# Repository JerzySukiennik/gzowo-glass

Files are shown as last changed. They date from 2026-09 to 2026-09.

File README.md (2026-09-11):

# Gzowo Glass — G.L.A.S.S.

Home-built smart glasses: a see-through HUD in front of the right eye (0.96" OLED →
fold mirror → f=50 lens → 50/50 beam splitter) driven by a XIAO ESP32-S3 Sense, with a
voice assistant (Gemini Live, Polish) running on a home server.
G.L.A.S.S. = *Gzowo Like A Smart Sass*.

## Repo layout

- `cad/glass.scad` — the print-ready parametric frame (OpenSCAD 2021.01). Source of truth.
- `cad/export-all.sh` — exports every part to `cad/stl/` (build output, wiped each run).
- `cad/glass_build.py` — Blender 4.5 script: imports the STLs, adds lenses/optics/mannequin, renders stills and a turntable into `renders/`.
- `SHOPPING.md` — parts list with prices.
- `RESEARCH.md` — what other DIY smart-glasses builds got right and wrong.

## Regenerate

```bash
cad/export-all.sh
/Applications/Blender.app/Contents/MacOS/Blender -b -P cad/glass_build.py -- stills
/Applications/Blender.app/Contents/MacOS/Blender -b -P cad/glass_build.py -- turntable
```

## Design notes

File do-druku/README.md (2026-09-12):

# do-druku — v0.6 (po przeglądzie gauntlet, przed drukiem)

Sześć części + 14 × M2,5×12 (2 zawiasy + 4 pokrywka daszka + 4 + 4 pokrywki podów).
Folder jest kopią `cad/stl/`, źródłem jest `cad/glass.scad`. Co się zmieniło i dlaczego: `GAUNTLET-REPORT.md`.

| Plik | Szt. | Orientacja na stole | Podpory |
|---|---|---|---|
| `front.stl` | 1 | **DO GÓRY NOGAMI**: górne krawędzie daszka i podów na stole (otwarte komory w dół) | brak w komorach; tree pod noskówkami i pod belką między podami |
| `lid_hood.stl`, `lid_r.stl`, `lid_l.stl` | 1+1+1 | płasko | brak |
| `temple_r.stl`, `temple_l.stl` | 1+1 | na boku, występ głośnika do góry | brim, bez podpór |

PLA, 0,2 mm, 3 ścianki, 20 %. Skala 1:1 (PD = 62 roboczo). Front 200 × 68 × 42 mm.

## Co jest inaczej niż w v0.3/v0.4

- Daszek nad prawym okiem jest wyższy (34 mm) i **otwarty od góry**: tam siedzi OLED (na szynach, przesuwny 6 mm = ostrość), jedno lusterko 30×30 (między żebrami pod 45°) i soczewka (w kieszeni w podłodze, nad szybką). Szybka 25×25 wchodzi od dołu w skośną szczelinę w podłodze daszka.
- Pody otwarte od góry, pokrywki na 4 śrubki. Prawy: wzmacniacz na żebrach + przycisk w pokrywce. Lewy: bateria przy ściance + XIAO za przednią ścianką (okno kamery), USB-C przez pokrywkę.
- Zawias: śruba z góry, 4 mm gwintu w dolnej kostce, łeb wystaje 2,5 mm. Zauszniki rozchylone na zewnątrz.
- Tył płaski, rowek na kable 5×5 na tylnej ścianie belki.

## Przymiarka (bez elektroniki)

Drukuj front + zauszniki (pokrywki opcjonalnie). Sprawdź: mostek nie dotyka nosa (VD 21), noskówki leżą płasko na bokach nosa, zauszniki nie uciskają przed uszami, daszek nie zasłania więcej niż górny skrawek widzenia prawego oka, szczelina szybki ≥ 2 cm od rzęs. Zgłoś liczby, wszystko jest parametrem.

## Do potwierdzenia po dostawie części

- Pozycja obiektywu kamery i USB-C na realnym XIAO (okno i wycięcie w pokrywce lewego poda).
- Offset aktywnego pola OLED względem środka płytki (`OLED_OFF`).
- Grubość szybki i lusterka (szczeliny liczone na 1,1 i 1,6 mm).

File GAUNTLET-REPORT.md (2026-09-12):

# Gauntlet: przegląd Gzowo Glass v0.4 (2026-09-12)

Jedna runda, tylko raport (decyzja Jurka). Czterech recenzentów (optyka i geometria: Opus 5, koszyk i elektronika: Sonnet 5), potem świeży, niezależny Critic (Opus 5), który przeliczył 21 twierdzeń liczbowych od zera: 18 zgodnych, 2 błędne poprawki, 1 nieodtwarzalne. Surowe pliki: `work/gauntlet/findings/*.md`, `work/gauntlet/critic.md`.

**Wynik: STOPPED, LIMIT REACHED (jedna runda). Werdykt Critica: CONDITIONAL PASS, 72/100.** Treść recenzji jest w większości prawdziwa, ale brakowało jednej wspólnej listy i rozstrzygnięcia pięciu sprzeczności między plikami. Ta lista jest poniżej, sprzeczności rozstrzygnąłem jako orchestrator, a poprawki wprowadziłem od razu w `cad/glass.scad` jako v0.6.

## Najważniejsze wnioski

1. **Optyka v0.4 dawała obraz, ale okrojony do 44 % pikseli.** Kanały wycięte pod rozmiar OLED-a (22×11), a wiązka na soczewce potrzebuje 38×21 mm. Soczewka stała 91 mm od oka, na złym końcu toru. Do tego trzy odbicia = obraz lustrzany. Werdykt optyki: „ONLY IF".
2. **Nic nie trzymało soczewki, OLED-a ani pierwszego lusterka.** Ich „kieszenie" były wycięte w pustej komorze poda, czyli nie istniały.
3. **Front był trzema osobnymi bryłami**, sklejonymi tylko wspólną płaszczyzną (x = ±66). Slicer scaliłby je przypadkiem albo wcale.
4. **Zauszniki rozchylały się do środka** (znak kąta odwrócony), o 35 mm w głowę przy uszach.
5. Ścianki 0,24–0,6 mm w daszku (za szczelinami na lusterko i szybkę), zawias z 3,5 mm gwintu i śrubą za krótką o 1,5 mm, rowek na kable na 4–6 żył zamiast 9, mostek 4–5 mm w nosie, noskówki obrócone w złą stronę.
6. Koszyk: suma to 140,25 zł, nie „~137"; dodać JST (~4 zł) i termokurczkę (~5 zł); szybka 25×25 wystarczy (wiązka na szybce 16,7×10,2); lusterko „first surface" za 7 zł to realne ryzyko podwójnego odbicia, test latarką po dostawie.
7. Elektronika: jeden XIAO ESP32-S3 Sense wystarcza (I2C na D4/D5, I2S na D0–D2, przycisk na D3, kamera i mikrofon na stałych pinach; dwa porty I2S). Ryzyko: szczyt prądu WiFi + kamera + głośnik przy ~600 mA regulatora; czas pracy ~2 h na 500 mAh, ~4 h na 1000 mAh.

## Rozstrzygnięcia sprzeczności (orchestrator)

| Spór | Decyzja | Uzasadnienie |
|---|---|---|
| Układ optyczny: dwa lusterka (v0.4) czy jedno (optyka §3) | **Jedno.** OLED w daszku na szynie x 60–66, lusterko 45° o oś Y, soczewka w podłodze daszka, szybka pod nią | 100 % pola, 24,7°, obraz nieodwrócony, jedno lusterko taniej. Critic wykrył kolizję soczewki Ø30 z szybką 30×30 w tym układzie; rozwiązane przez szybkę 25×25 i soczewkę na z = 13,4 (przeliczone: przerwa 0,5 mm) |
| Szybka 30×30 vs 25×25 | **25×25×1,1** | Wiązka na szybce 16,7×10,2; 30 mm koliduje z soczewką |
| Liczba lusterek w koszyku | **1 × 30×30** | Wynika z układu |
| Gdzie MAX98357 | **Prawy pod, przy zewnętrznej ściance, na żebrach** | OLED nie jest już w podzie, więc spór o tor ostrości znika |
| `OLED_OFF` 4 vs ≤ 0 | **0 do czasu pomiaru suwmiarką** | Board stoi teraz w daszku między żebrami, nie w podzie; offset ustawiany po dostawie |
| Rowek na 9 żył | **Rowek 5×5 na belce 8 mm** (zamiast 6 mm) | Geometria ma rację, 3,2×3,7 mieści 4–6 żył |
| Zawias (poprawka geometrii #10 dawała 2,3 mm gwintu) | **Kostki 8 / 5 / 2, luzy 0,5, łeb wystaje** | Policzone od nowa: koniec śruby 4 mm w gwintowanej dolnej kostce, 12 mm trzonu wystarcza |
| VD 18 vs skan | **VD 21** | Mostek siedział 4–5 mm w nosie przy z = −12…−15 |
| Kolor OLED | **Biały** | Jurek, 2026-09-12 |

## Lista poprawek (wszystkie wprowadzone w v0.6, chyba że zaznaczono)

| # | Ważność | Co | Stała / moduł w SCAD | Test |
|---|---|---|---|---|
| 1 | S1 | Jeden układ optyczny z jednym lusterkiem, OLED w daszku | `MIR_C`, `LENS_Z`, `OLED_X0/X1`, `COMB`, `BS` | `part="fit"`: duchy OLED, lusterka, soczewki i szybki bez przecięć; po dostawie: pełna ramka 1 px widoczna z 4 stron |
| 2 | S1 | Pozytywne mocowania: szyny OLED, żebra lusterka, kołnierz soczewki w podłodze | `hood_holders()` | Wydruk odwrócony: soczewka trzyma się bez kleju |
| 3 | S1 | Front jako jedna bryła (daszek wchodzi 2 mm w pod, belka 8 mm) | `HOOD_X1 = 68`, `front_solid()` | Eksport STL: jedna powłoka |
| 4 | S1 | Rozchył zauszników na zewnątrz | `rotate([0,0,+s*TEMPLE_SPLAY])`, 15° | Widok z góry ze skanem: zausznik na zewnątrz głowy |
| 5 | S2 | Daszek i pody otwarte od góry, pokrywki na M2,5×12, bez cienkich ścianek za szczelinami | `hood_cavity()`, `lid_hood()`, `lid_pod()` | Ray-cast na STL: każda ścianka ≥ 1,2 mm |
| 6 | S2 | Zawias 8/5/2, luz 0,5, tylna ścianka poda 3 mm, blok kostek 6 mm w pod | `HK_*`, `BACK_W` | Sekcja z = 14: ciągły materiał od kostki do ścianek |
| 7 | S2 | Rowek 5×5 na tylnej ścianie belki 8 mm, koniec przy daszku, przelot do daszka i do prawego poda | `GROOVE`, `BAR_T` | 8 żył 1,5 mm mieści się (3×3 siatka) |
| 8 | S2 | Szybka 25×25, szczelina przez podłogę daszka z fazką (bez ostrza) | `hood_cuts()` | Ray-cast na podłodze przy szczelinie ≥ 1,2 mm |
| 9 | S2 | VD 21, noskówki obrócone w stronę policzka i pochylone | `VD`, `PAD_ANG = +40`, `PAD_TILT = 22` | Przymiarka wydruku: mostek nie dotyka nosa, noskówki płasko |
| 10 | S3 | Przycisk w pokrywce prawego poda (klatka 6,4 mm + otwór Ø4,2) | `lid_pod(1)` | Przełącznik nie wypada, klik wyczuwalny |
| 11 | S3 | Kamera: okno Ø7 + odciążenie Ø10 na wysokości płytki, USB-C w pokrywce lewego poda | `pod_cuts(-1)`, `lid_pod(-1)` | **Do potwierdzenia na realnej płytce** (pozycja złącza i obiektywu) |
| 12 | S3 | Głośnik: kieszeń z kratką 0,8 mm od strony głowy, kanał na kable wychodzi na czole zausznika | `temple_body()` | Przewody przechodzą z poda do kieszeni bez wiercenia |
| 13 | S3 | Kanał wiązki w daszku 22×14 (okno w podłodze), oś na z = 22 | `BEAM_Z`, `hood_cuts()` | Ray-trace z `optics.md` z nowymi aperturami: ≥ 95 % pikseli |
| 14 | v0.7 | Przyciemnienie **przed** szybką (płytka przed daszkiem) zamiast w obręczy | brak | Kontrast HUD:świat rośnie 0,93 → 4,7 |
| 15 | v0.7 | Szybka 70R/30T zamiast 50/50 | koszyk | Kontrast ×2,3 |
| 16 | koszyk | Dopisać JST-PH, termokurczkę; jedno lusterko; szybka 25×25 | `SHOPPING.md` | Suma po zmianie |
| 17 | firmware | Rejestr SSD1306: przy dwóch odbiciach obraz prosty, bez remapu; sprawdzić literą „R" | firmware | „R" czytelne przez szybkę |

## Czego raport nie rozstrzyga (uczciwie)

- Geometria v0.6 (nowy daszek 34 mm wysoki, otwarte komory, pokrywki) **nie była audytowana** przez recenzenta geometrii; to nowa część. Pierwszy test to eksport STL i tabela grubości ścianek, drugi to wydruk samego frontu.
- Wymiary XIAO Sense (wysokość obiektywu, pozycja USB-C) i offset aktywnego pola OLED są z datasheetów i domysłów, nie z pomiaru. Okna w lewym podzie i pokrywce poprawić po dostawie.
- Skan głowy jest w skali roboczej (PD 62). Każdy milimetr błędu PD to ±3 % wszystkich odległości.
- Jasność: HUD czytelny w pomieszczeniu i w cieniu, nie w pełnym słońcu (potrzebny byłby filtr T ≤ 0,005). To ograniczenie SSD1306, nie geometrii.

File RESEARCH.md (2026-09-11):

# Gzowo Glass — jak inni zbudowali DIY smart glasses (research 2026-09-11)

Siedem projektów, które robiły to samo co my. Co zrobili, co im nie wyszło i co z tego bierzemy.

## 1. E.D.I.T.H — AbrarFairuj, Instructables 2022 (ten od Jurka)
https://www.instructables.com/EDITH-How-Did-I-Build-a-Powerful-Smart-Glass-Under/

- **Sprzęt:** Raspberry Pi Zero (bez W!) + hub USB + dongle WiFi + dongle BT + mikrofon USB, OLED 0,96" I2C, głośnik z pinów PWM przez filtr RC + tranzystor, bateria 4000 mAh z modułem powerbanka. ~35 $.
- **Optyka:** OLED pod 22,5°, „szkło" (płaska szybka) pod 45°. **Bez soczewki.** Autor sam pisze, że użył płaskiego szkła, „żeby nie zmieniać rozmiaru obrazu" — efekt: oko musi ostrzyć na ekran z 3–5 cm, czego nie potrafi, więc obraz jest rozmyty. Dokładnie ten błąd omijamy soczewką.
- **Software:** Node na Pi, Dialogflow jako „AI", apka React Native na telefonie przesyła po Bluetooth pogodę/SMS/powiadomienia.
- **Sam przyznaje:** „bardzo duże, ciężkie, nie do noszenia", tydzień na samo postawienie OS-u, Pi Zero żre prąd (2000 mAh na chwilę). V2 „na własnej płytce z 8 rdzeniami" nigdy nie powstała.
- **Wniosek:** nasza decyzja XIAO zamiast Pi Zero i soczewka w torze to dokładnie naprawa jego dwóch największych problemów.

## 2. Arduino Glasses — Alain Mauer, hackaday.io (HMD do multimetru)
https://hackaday.io/project/12211-arduino-glasses-a-hmd-for-multimeter

- **Najlepiej policzona optyka z całej listy.** Soczewka plano-convex Ø30 mm, **f = 100 mm**, OLED **73 mm** od soczewki → obraz pozorny w odległości 27–30 cm, powiększenie 3×. Celowo 27–30 cm, bo to minimalna odległość, na którą oko ostrzy wygodnie.
- Lusterko pod 45°, uchwyt drukowany 3D. 0,96" OLED uznał za za duży, przeszedł na 0,49"/0,66" (chciał małe, my nie musimy).
- Arduino Pro Micro + HM-11 BLE, LiPo 280 mAh.
- **Problemy:** trudno kupić soczewkę (rozważał Fresnela), ekran odbijający wygiął się od ciepła, bez drukowanego uchwytu nie dało się utrzymać wyrównania.
- **Wniosek dla nas (liczby dla f = 50 mm):** OLED **bliżej niż ogniskowa** daje obraz pozorny w skończonej odległości:
  - 42 mm → obraz ~26 cm, powiększenie ~6× (OLED 22 mm szeroki wygląda jak ~14 cm na 26 cm, ~30° pola widzenia)
  - 45 mm → obraz ~45 cm, ~10×
  - 48 mm → obraz ~1,2 m
  - 50 mm → nieskończoność
  Uchwyt musi mieć **regulację 38–50 mm**, nie stałą pozycję. To potwierdza ryzyko z notatki projektu.

## 3. uGlass — moduł AR na okulary, hackaday.io
https://hackaday.io/project/167854-uglass-an-ar-module-on-your-glasses

- SSD1306 OLED + soczewka z Google Cardboard + **szkiełko mikroskopowe jako combiner**, hot glue na zwykłe okulary. nRF52832 + IMU.
- **Co się wysypało na Maker Faire:** pole widzenia za wąskie i zależne od położenia okularów na nosie („wielu ludzi nic nie widziało"); okrągła soczewka wystawała i **dotykała oka**.
- Ich wniosek: mniejszy ekran o większej gęstości pikseli, mniejsza soczewka, krótsza ogniskowa.
- **Wniosek dla nas:** soczewka jest nad okiem, nie przed nim — u nas nie dotknie oka. Combiner 30×30 mm zamiast szkiełka daje większe „okno". Oprawka drukowana na twarz Jurka zamiast klipsa = powtarzalne położenie.

## 4. Ochi — Harris Shallcross, Hackaday 2016 „why smart glasses are hard"
https://hackaday.com/2016/06/26/homemade-smart-glasses-shows-why-smart-glasses-are-hard/

- 0,95" 96×64 **kolorowy** OLED, soczewka z Cardboarda, **drukowany uchwyt przesuwany po drucianej szynie do regulacji ostrości**, STM32 + HM-11 BLE, Li-Ion + boost, apka Android.
- Lekcje: rozkład masy na głowie decyduje o komforcie; „wyświetlenie danych to połowa roboty, druga to CO i KIEDY pokazać".
- **Wniosek dla nas:** regulacja ostrości jako prowadnica z zaciskiem — bierzemy. Masa: bateria po tej samej stronie co elektronika obciąża jedno ucho; rozważyć baterię w lewym zauszniku jako przeciwwagę (kabel przez front).

## 5. Beady-i — XenonJohn, Instructables 2013
https://www.instructables.com/DIY-Google-Glasses-AKA-the-Beady-i/

- Nie DIY-optyka: przecięte gotowe okulary wideo Myvu Crystal + sprężysta opaska z headsetu. Inna droga niż nasza.
- Jedna przydatna uwaga: wyświetlacz da się ustawić bardzo blisko oka i nadal ostrzyć „na daleko", ale **za blisko = rzęsy uderzają w szkło przy mruganiu**. Combiner minimum ~20 mm od rogówki.

## 6. OpenGlass — BasedHardware (XIAO ESP32-S3 Sense, 20 $)
https://github.com/BasedHardware/OpenGlass · https://www.seeedstudio.com/blog/2024/05/23/openglass-turn-any-glasses-into-ai-smart-glasses-for-just-20-with-xiao-esp32s3-sense/

- **Ten sam moduł co nasz.** XIAO Sense + LiPo 250 mAh + drukowany klips na okulary. Zdjęcia i audio po **BLE do apki** (React Native/Expo), AI: Groq / OpenAI / Ollama moondream. Bez wyświetlacza.
- Repo zdeprecjonowane (projekt przeszedł w Omi), ale folder `firmware/` to gotowy szkic Arduino: kamera + mikrofon + BLE na XIAO Sense. Dobry punkt startowy do naszego firmware'u kamery.

## 7. Voice-Assistant-Camera-Wearable — xanderchinxyz
https://github.com/xanderchinxyz/Voice-Assistant-Camera-Wearable

- XIAO Sense, 220 mAh, drut dotykowy na D0 jako przycisk, BLE → Python na desktopie: VOSK (STT) → Groq (LLM+RAG) → pyttsx3 (TTS), moondream do obrazu. Bez wyświetlacza, bez głośnika w okularach.
- **Wniosek:** wszyscy na XIAO robią BLE do telefonu i mówią przez komputer. My idziemy krok dalej (WiFi + WebSocket + Gemini Live + HUD + głośnik w okularach) — nikt z tej listy tego nie połączył, ale każdy klocek osobno jest sprawdzony.

## Problemy powtarzające się w kilku projektach

- **Wypalanie OLED-a** po ~2 miesiącach codziennego statycznego UI → firmware: wygaszenie po ~10 s bezczynności, przesuwanie statycznych elementów o 1 px co kilka minut, jasność nie na maksa.
- **Wyrównanie optyki** to główna robota, nie elektronika. Każdy, kto nie miał drukowanego uchwytu, walczył z hot glue. Zasada: najpierw „klocki Lego" (OLED + soczewka + lusterko trzymane w ręku), dopiero potem CAD.
- **Pole widzenia** wąskie i wrażliwe na położenie na nosie → oprawka na miarę twarzy.
- **Waga i rozkład masy** — Pi Zero + 4000 mAh to koniec noszenia. XIAO + 500 mAh ≈ 25 g elektroniki.
- Audio przez BLE gubi pakiety przy odświeżaniu ekranu (u nas WiFi, nie dotyczy).
- Fresnel jako lekka alternatywa soczewki — jeśli szklana okaże się za ciężka/za gruba, opcja B.

## Co zmieniamy w planie po researchu

1. Uchwyt OLED z regulacją **38–50 mm** od soczewki (prowadnica + zacisk, jak Ochi), nie ±5 mm.
2. Combiner **≥ 20 mm** od oka (rzęsy), soczewka nad okiem nigdy w polu widzenia.
3. Firmware: **ochrona OLED** (wygaszanie, pixel shift, jasność ~60%).
4. Bateria rozważana w **lewym** zauszniku jako przeciwwaga.
5. Firmware kamery/mikrofonu na XIAO Sense: zacząć od szkicu z OpenGlass `firmware/`, nie od zera.

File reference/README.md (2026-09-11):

# reference/

Local-only inputs (gitignored): `head-scan.glb` (photogrammetry scan of Jurek, 2026-09-11), `head-aligned.blend`, `head-mm.blend`, `head-mm.stl` (aligned: origin between the pupils on the cornea plane, X right, Y forward, Z up, mm; scaled to PD = 62 provisionally), `landmarks-mm.json`.

Regenerate from the GLB with the scripts in the session scratchpad (scan_align.py, scan_refine.py) — to be moved into `tools/` when stable.

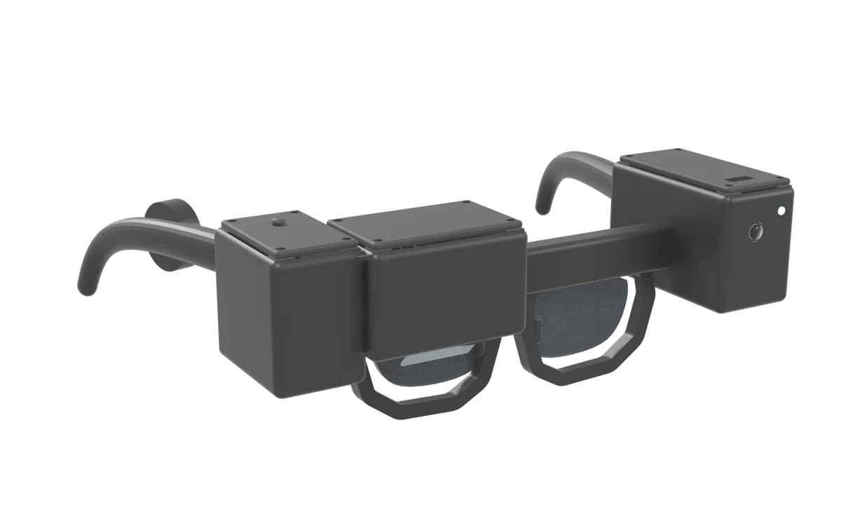
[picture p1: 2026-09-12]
docs/glass/assets/v0.6/frames/f008.webp

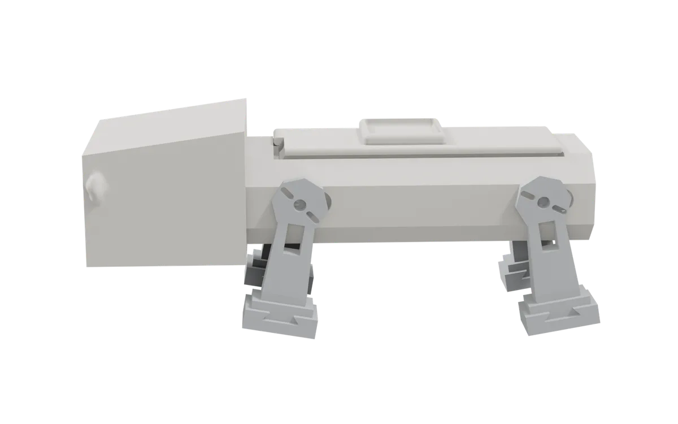
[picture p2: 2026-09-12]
docs/smendilendi/assets/v0.5/frames/f089.webp

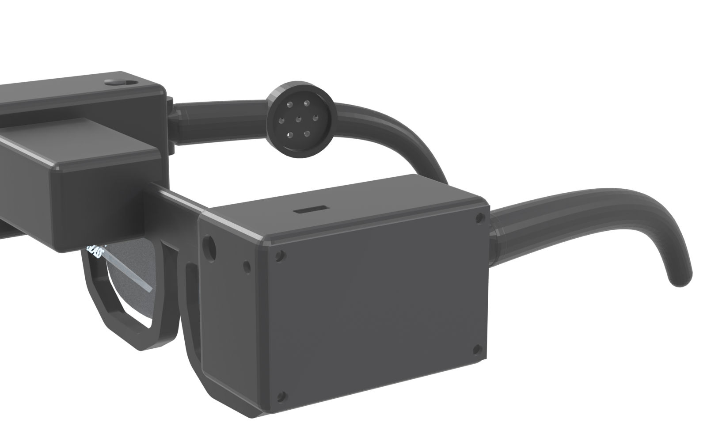
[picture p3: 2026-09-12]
renders/frames/f081.png

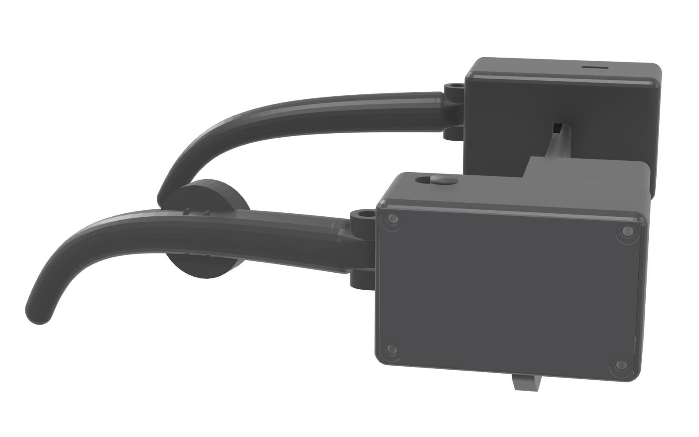
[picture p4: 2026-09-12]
renders/frames/f021.png

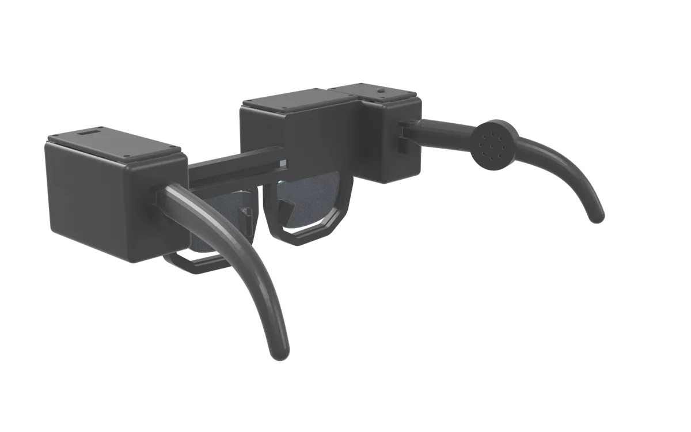
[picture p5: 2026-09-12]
docs/glass/assets/v0.6/frames/f060.webp

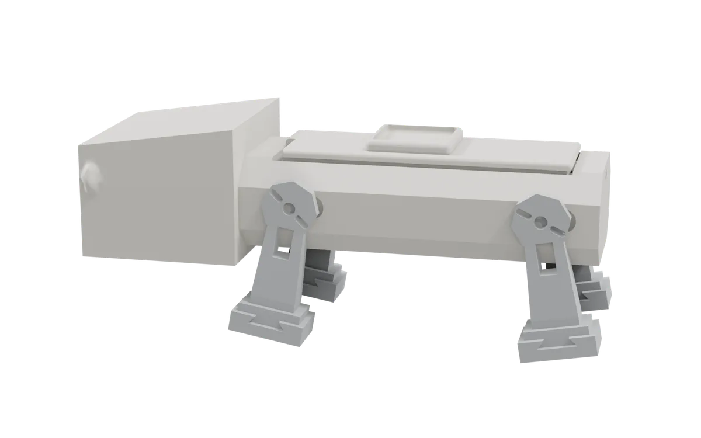
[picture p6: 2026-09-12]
docs/smendilendi/assets/v0.5/frames/f085.webp

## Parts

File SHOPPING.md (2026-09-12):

# Gzowo Glass — koszyk v1 (AliExpress, jedno zamówienie)

Ceny sprawdzone 2026-09-10 na pl.aliexpress.com (mogą się ruszać o kilka zł).
Ali ~120 zł, bateria z domu. Budżet 250 zł z dużym zapasem. Zamawia Jurek.

| # | Część | Link | Cena | Wariant do wybrania |
|---|---|---|---|---|
| 1 | **Seeed XIAO ESP32-S3 Sense** (mózg: kamera OV2640, mikrofon, 8 MB PSRAM, WiFi/BLE, ładowarka LiPo) | https://pl.aliexpress.com/item/1005006988111963.html | 65,59 zł | „1pc" (jeden wariant, kamera OV3660), dostawa 17–24 wrz |
| 2 | **OLED 0,96" 128×64 I2C SSD1306** (wyświetlacz do combinera) | https://pl.aliexpress.com/item/1005009170035050.html | 8,40 zł | kolor **biały** (Jurek, 2026-09-12), 4-pin IIC, 1 szt. |
| 3 | **Beam splitter 25×25 mm** (półprzezroczyste lustro, combiner przed okiem) | https://pl.aliexpress.com/item/1005012046261289.html (wybierz wariant 25×25, jeśli jest; inaczej szukaj „beam splitter 25x25 50/50") | ~30 zł | **25×25 mm**, 50/50, grubość ≤ 1,5 mm (v0.6: 30 mm kolidowało z soczewką; wiązka na szybce ma 17×10) |
| 4 | **Soczewka Ø30 mm, f = 50 mm** (dwuwypukła, szkło) | https://pl.aliexpress.com/item/1005004213353520.html | ~3 zł | wariant **D30mm FL50mm** (25 mm nie ma w tym listingu; 30 jest OK) |
| 5 | **Wzmacniacz I2S MAX98357** (dźwięk z ESP32 do głośnika) | https://pl.aliexpress.com/item/1005009356741606.html | 5,51 zł | 1 szt. |
| 6 | **Głośnik 20 mm, 8 Ω, 1 W, ultracienki 3,6 mm** (2 szt. w paczce, zapas) | https://pl.aliexpress.com/item/1005009193787692.html | 3,84 zł | 20×3,6 mm |
| 7 | **LiPo 3,7 V, 300–1000 mAh — Z DOMU** (Ali nie wysyła ogniw do PL, Botland = płatna dostawa). Każde ogniwo 1S z drona/powerbanka/słuchawek; ważne: 1 cela 3,7 V, nie 7,4 V | — | 0 zł | jak nic nie znajdziesz: Botland Akyga 620 mAh 40×20×8 mm, 20,90 zł (AKU-15606) |
| 9 | **Mikroprzyciski 6×6 mm tact, 20 szt.** (przycisk na podzie) | https://pl.aliexpress.com/item/1005005845072975.html | 3,73 zł | 6×6×5 mm lub 6×6×7 mm |
| 10 | **Lusterko powierzchniowe (first surface mirror) 30×30 mm, 1 szt.** — w daszku, zawraca wiązkę z OLED-a w dół na szybkę (v0.6: jedno lusterko zamiast dwóch) | szukaj na Ali: „first surface mirror 30x30" (~5–8 zł) | ~7 zł | 30×30, ≤ 2 mm, **powierzchniowe** (zwykłe lusterko daje podwójne odbicie; test po dostawie: latarka pod kątem, ma być jedno odbicie) |
| 11 | **Złączki JST-PH 2-pin** (bateria odłączalna) | Ali: „JST PH 2.0 2pin connector" | ~4 zł | 10 par |
| 12 | **Termokurczka, zestaw** (14 lutów w ciasnym podzie) | Ali: „heat shrink tube kit" | ~5 zł | 1–4 mm |
| | **Razem** | | **~137 zł** (samo Ali) | |

## Zanim klikniesz „kup"

- **Poz. 1 — zmiana 2026-09-10 wieczorem.** Pierwotny link (4000011805115, „45,49 zł") pokazywał domyślnie **samo złącze pinowe za 2,09 zł**, a dostawę 18 lis – 3 gru. Zastąpiony listingiem z jednym wariantem, 1000+ sprzedanych, dostawa w tydzień. Kamera OV3660 (2048×1536) zamiast OV2640 — dla nas tylko lepiej.
- **Sprawdzaj datę dostawy przy KAŻDEJ pozycji.** Ali sortuje po cenie z najtańszego wariantu (goldpiny, sam kabel, 1 szt. z partii), więc niska cena na liście nie znaczy niska cena tego, co chcemy. Zasada: po wybraniu wariantu cena i „Dostawa: …" mają wyglądać rozsądnie, inaczej szukaj innego sprzedawcy tego samego produktu.
- **Poz. 7, bateria — z domu.** Sprawdzone 2026-09-11: żaden LiPo z Ali nie wysyła do Polski, a Botland liczy za dostawę. Jurek szuka ogniwa w domu. Wymagania: **jedna cela Li-Po/Li-Ion 3,7 V** (na naklejce 3.7V, nie 7.4V), 300–1000 mAh, najlepiej płaski „pouch" do 9 mm grubości, z dwoma przewodami. Ogniwo 18650 też zadziała, tylko nie zmieści się w zauszniku — do testów na biurku ok.
- **Przewody:** zamiast silikonowych 28 AWG używamy starych jumperów F-F/M-M z uciętymi końcówkami (24–26 AWG, w v1 wystarczy). Pozycja usunięta z koszyka.
- **Poz. 3, beam splitter:** jeśli 36 zł boli, tańsza alternatywa to 50:50 K9 za 31,33 zł (https://pl.aliexpress.com/item/1005010313219927.html), ale sprawdź w opisie rozmiar — potrzebujemy min. 25×25 mm.
- **Głośnik:** najpierw sprawdź szufladę. Jeśli masz jakikolwiek 8 Ω, poz. 6 odpada (i tak 3,84 zł, więc zapas nie boli).

## Czego NIE zamawiamy z Ali (masz / robisz sam)

- **Ciemne „szkła" oprawki** — najtańsze okulary przeciwsłoneczne z Pepco/Action (5–10 zł) i wycinamy z nich soczewki pod wydruk. Kolor nieistotny, chodzi o kontrast HUD-u.
- **Filament** — X1C, PLA czarny albo matowy ciemnoszary.
- **Włącznik zasilania** — nie potrzebny: przytrzymanie przycisku = deep sleep. XIAO w deep sleep ciągnie tyle, że 500 mAh starcza na tygodnie czuwania.
- **Kabel USB-C** — do wgrywania firmware i ładowania, masz.

## Po dostawie — pierwszy test w 30 minut

1. XIAO + OLED (4 przewody: 3V3, GND, SDA→D4, SCL→D5) → wgrać test „Hello GLASS".
2. OLED + soczewka + beam splitter trzymane w ręku pod 45° → czy widać ostry napis „w powietrzu"? Odległość OLED↔soczewka ≈ 45–50 mm. To rozstrzyga geometrię oprawki zanim cokolwiek wydrukujemy.

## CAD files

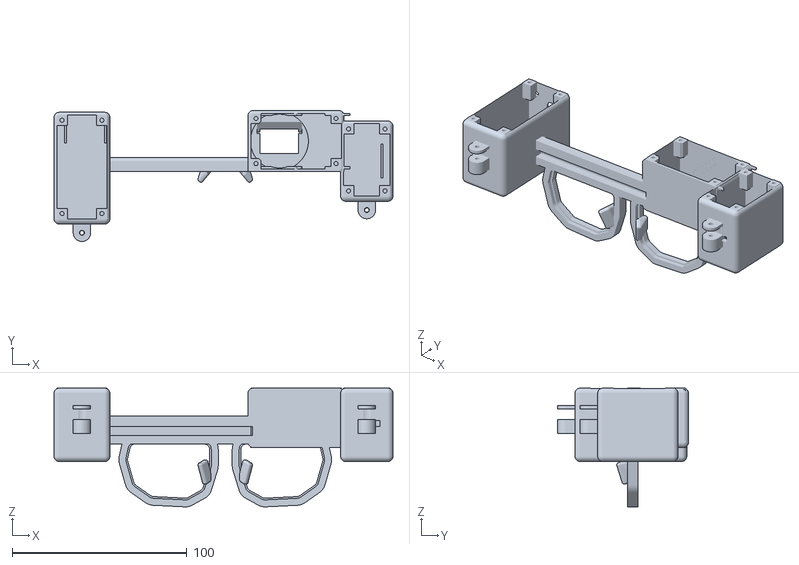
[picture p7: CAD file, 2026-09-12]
do-druku/front.stl
194.0 x 75.0 x 68.0

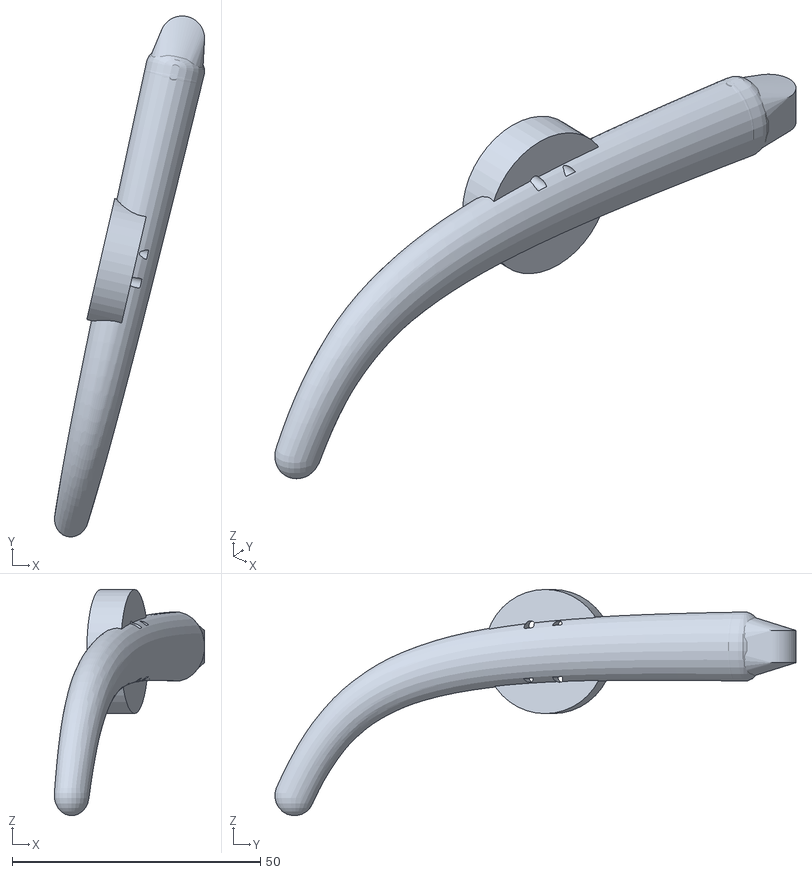
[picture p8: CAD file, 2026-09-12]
glass-fit-test-v0.4/temple_r.stl
30.2 x 104.9 x 45.5

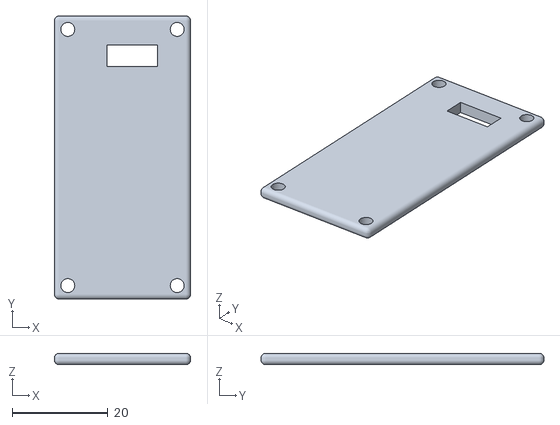
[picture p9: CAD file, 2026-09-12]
do-druku/lid_l.stl
28.4 x 59.0 x 2.40

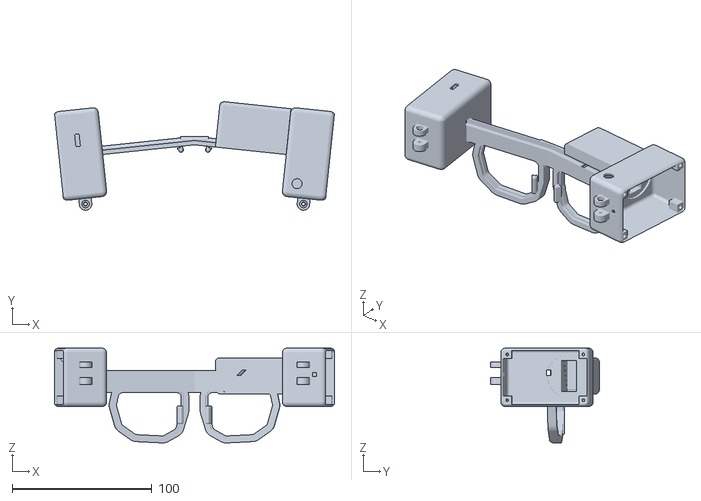
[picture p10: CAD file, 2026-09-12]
glass-fit-test-v0.4/front.stl
200.5 x 77.8 x 67.9

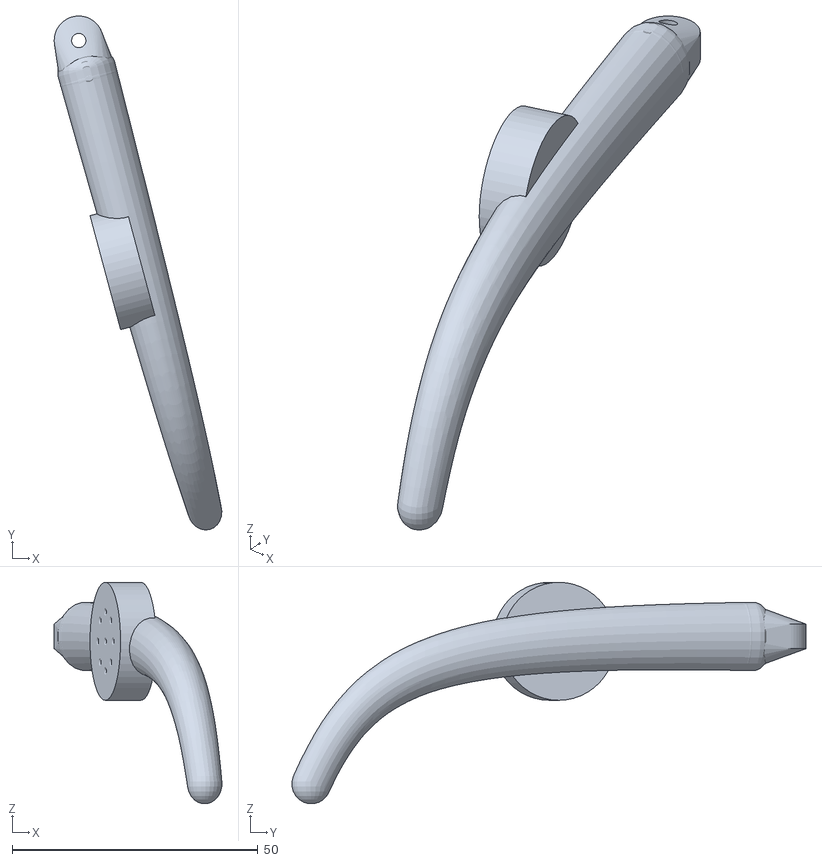
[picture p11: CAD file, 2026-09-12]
do-druku/temple_r.stl
34.1 x 104.6 x 45.0

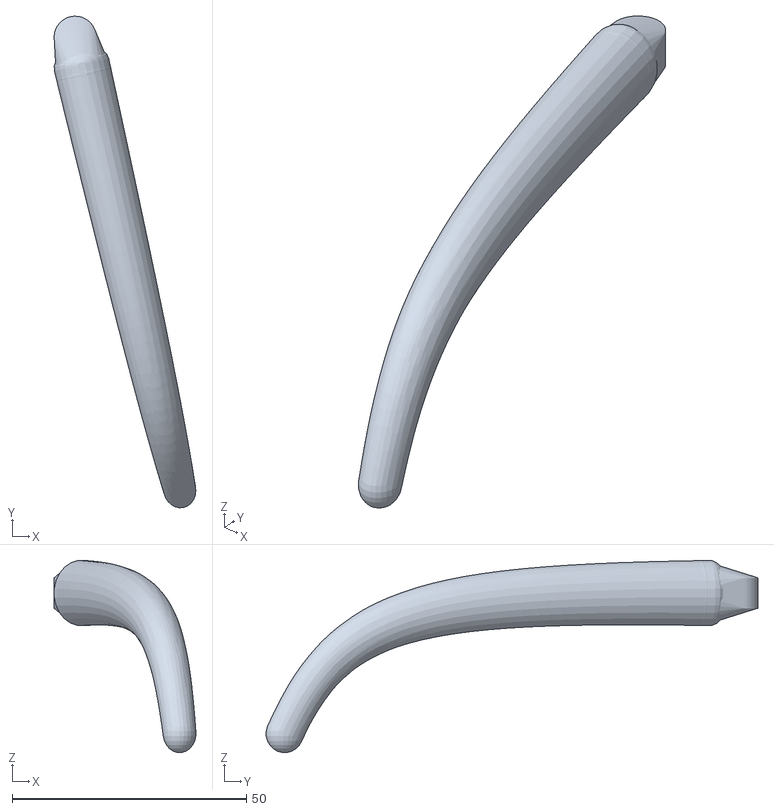
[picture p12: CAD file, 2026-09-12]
glass-fit-test-v0.4/temple_l.stl
30.2 x 104.9 x 41.0

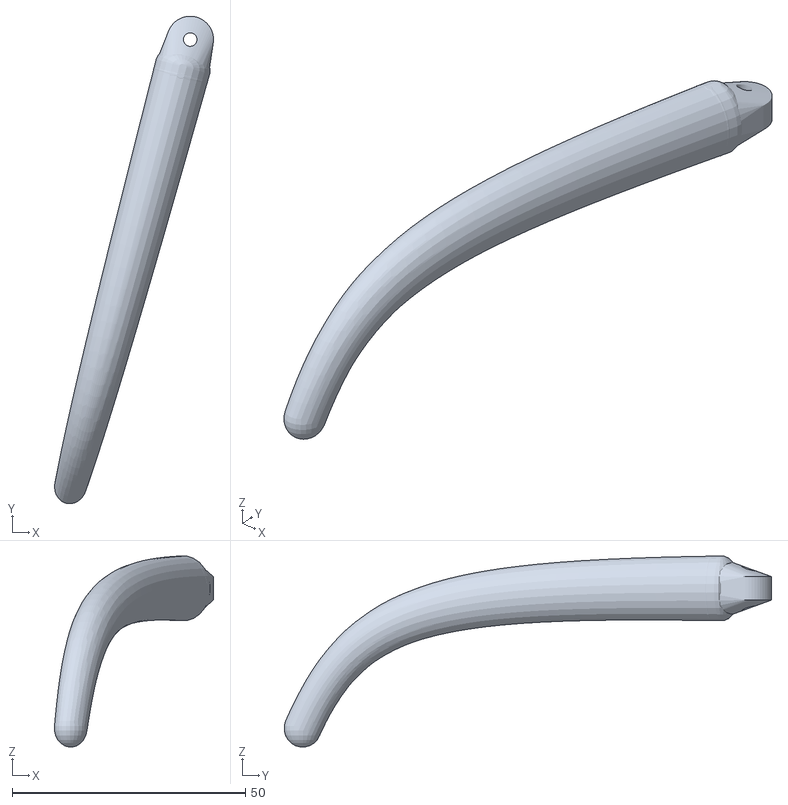
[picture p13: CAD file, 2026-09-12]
do-druku/temple_l.stl
34.1 x 104.6 x 41.0

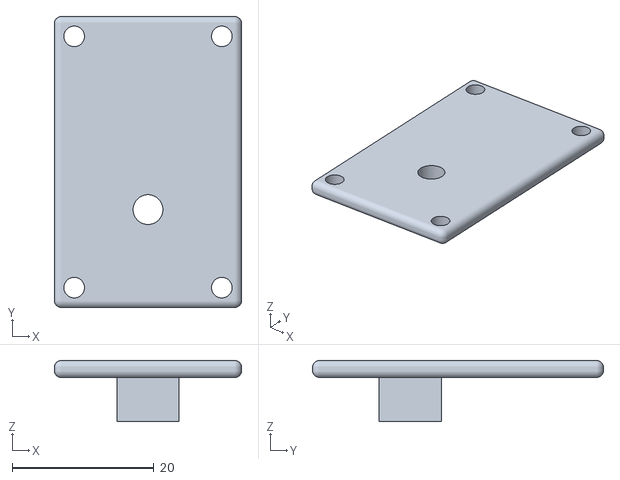
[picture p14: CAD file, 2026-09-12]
do-druku/lid_r.stl
26.4 x 41.0 x 8.60

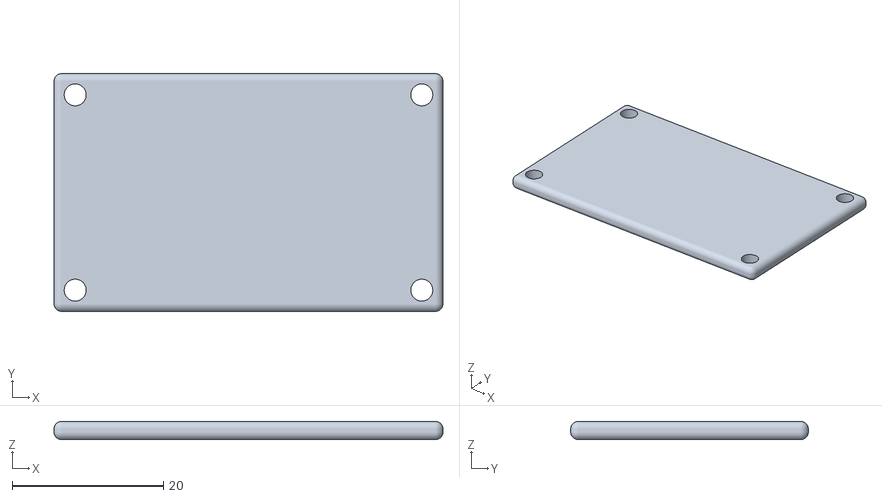
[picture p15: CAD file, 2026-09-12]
do-druku/lid_hood.stl
51.4 x 31.4 x 2.40

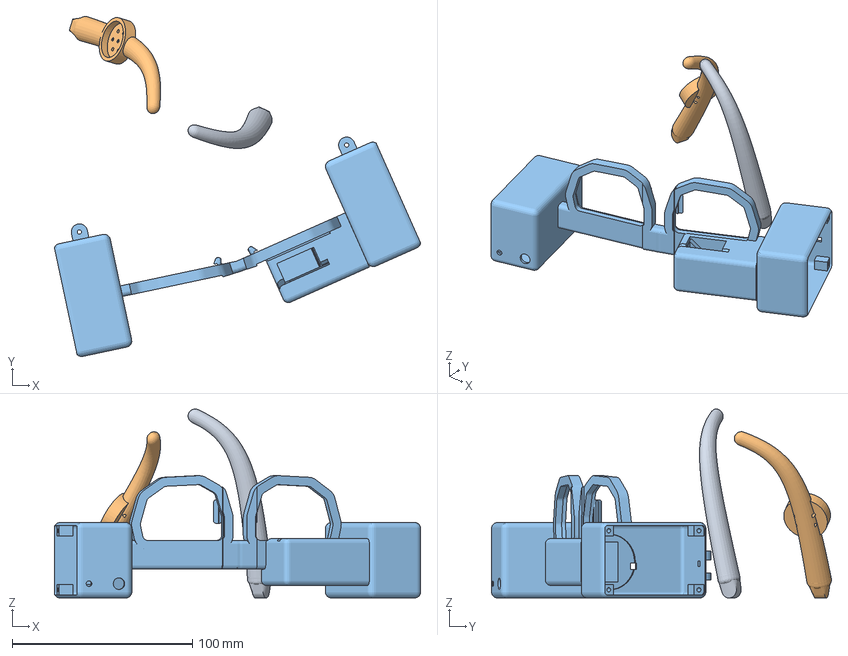
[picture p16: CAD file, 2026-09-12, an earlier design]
glass-fit-test-v0.2/front.3mf
203.3 x 188.7 x 104.9 mm
temple_l.stl
temple_r.stl
front.stl

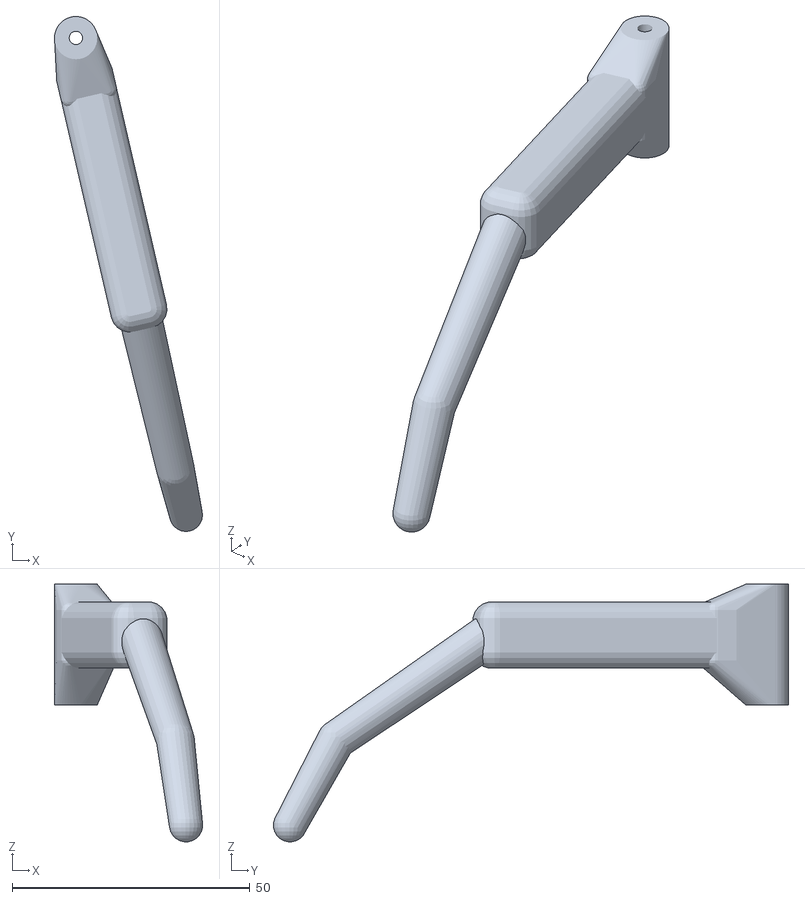
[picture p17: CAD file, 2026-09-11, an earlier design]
glass-fit-test-v0.2/temple_l.stl
31.1 x 108.3 x 54.2

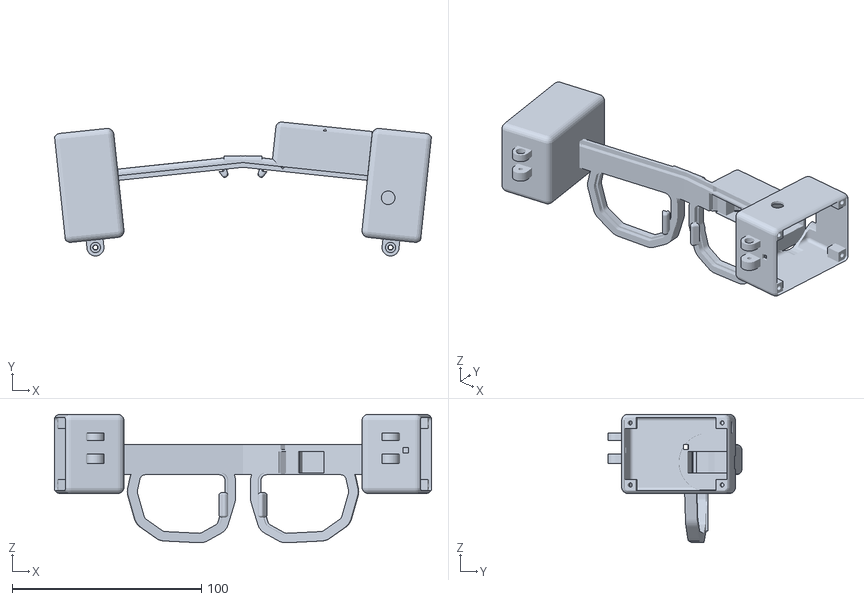
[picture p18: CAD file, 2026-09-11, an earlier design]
glass-fit-test-v0.3/front.stl
199.3 x 70.8 x 67.9

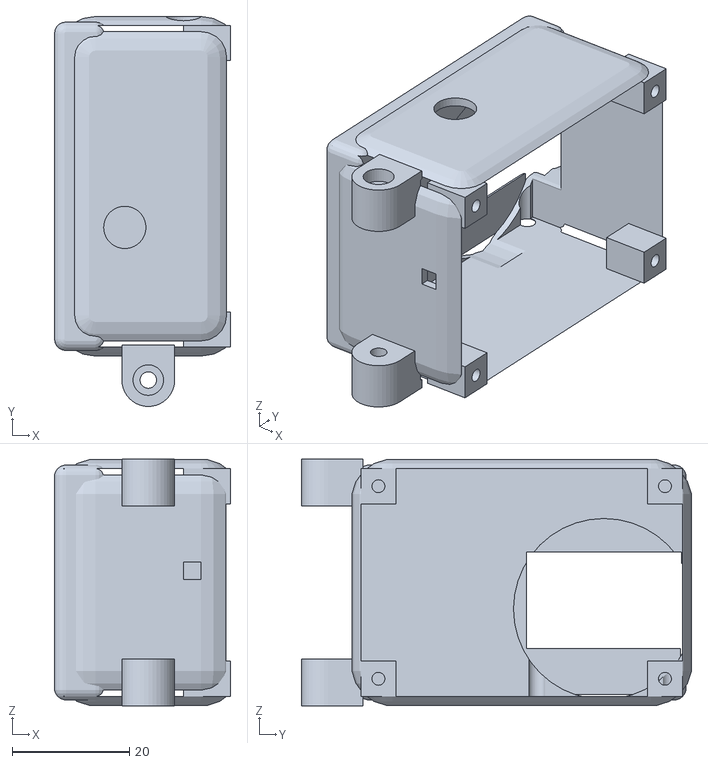
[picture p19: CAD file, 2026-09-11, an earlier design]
glass-fit-test-v0.2/pod_r.stl
30.0 x 66.4 x 42.0

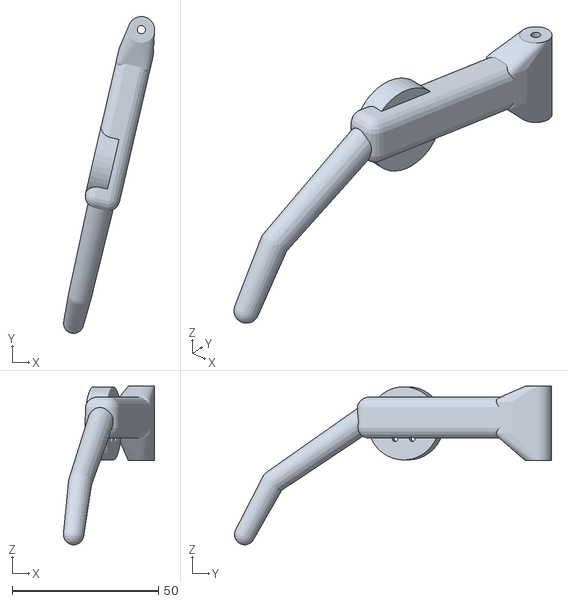
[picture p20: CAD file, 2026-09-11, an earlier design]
glass-fit-test-v0.2/temple_r.stl
31.1 x 108.3 x 54.2

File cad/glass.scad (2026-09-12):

// Gzowo Glass v0.6 — print-ready parametric frame (OpenSCAD 2021.01)
// ---------------------------------------------------------------------------
// Frame of reference (mm): X = wearer's right, Y = forward (away from the
// face), Z = up. The right pupil axis is the line (PD/2, *, 0). The back face
// of the front frame is the plane y = 0; the cornea sits at y = -VD.
//
// v0.6 rewrite after the gauntlet review (work/gauntlet/findings):
//   * SINGLE-FOLD OPTICS. The OLED stands in the hood (screen facing -X, long
//     axis along Z) on a slide rail x 60..66 (focus). One first-surface mirror
//     at 45° about Y turns the beam down; the lens f=50 sits in the hood floor
//     right above the beam splitter; the splitter (25x25) is tilted 45° about
//     X on the pupil axis. Two reflections -> upright, un-mirrored image.
//     do = 38..44 mm, lens->eye 47 mm, FOV ~24.7° x 12.5°, image 20..39 cm.
//   * Everything that holds a part is a POSITIVE feature (rails, ribs, floor
//     boss), never a slot that thins a 1.6 mm wall.
//   * The hood and both pods are open at the TOP and closed by lids (M2.5x12,
//     tapped bosses). Print the front UPSIDE DOWN (+Z on the bed): the open
//     cavities face the bed, so the front needs no internal supports.
//   * Pods are fused into the bar/hood with a 2 mm overlap (one solid).
//   * Hinge: bottom knuckle 8 (tapped), temple 5, top 2, gaps 0.5, M2.5x12
//     from the top, 4 mm of thread, head proud. Temples splay OUTWARD.
//   * Wire groove 5x5 on the back of a thicker (8 mm) bar, ends at the hood.
//   * Tinted lens in front of the combiner is a v0.7 item (contrast x5).
// Electronics: LEFT pod = XIAO ESP32-S3 Sense (camera front, USB-C up) +
//   battery. RIGHT pod = MAX98357 + button (in the lid). HOOD = OLED + mirror + lens.
// ---------------------------------------------------------------------------

part = "assembly";   // front | lid_hood | lid_r | lid_l | temple_r | temple_l | assembly | fit | layout | exploded
show_parts = true;   // ghost electronics/optics in assembly/fit
show_head = true;    // ghost of Jurek's head scan (reference/head2-mm.stl)
head_file = "../reference/head2-mm.stl";
$fn = 48;

// ------------------------------------------------------------ head / fit ---
PD       = 62;    // pupil distance (provisional; scan scaled to this)
VD       = 21;    // vertex distance: cornea -> frame back (v0.6: 18 -> 21, the bridge sat inside the nose)
DBL      = 18;    // distance between lenses
PAD_X    = 11.5;  // nose pad centre x
PAD_ANG  = 40;    // pad face angle about Z (deg): face points outward-and-forward like the nose flank
PAD_TILT = 22;    // pad face tilt about X (deg): flank leans back toward the eye
TEMPLE_L = 63;    // hinge -> start of the ear bend
EAR_DROP = 24;    // temple z -> ear top
TEMPLE_SPLAY = 15; // deg, temples open OUTWARD from the hinge (v0.4 had the sign inverted)
EX       = PD/2;

// ------------------------------------------------------- component sizes ---
XIAO     = [21, 17.8, 15];      // XIAO ESP32-S3 Sense stack incl. camera board (x, y footprint; z height of the stack)
OLED_PCB = [27.3, 27.3, 4.3];   // 0.96" I2C module board (w, h, thickness incl. pins). Active area 21.7x10.9.
AMP      = [19.4, 17.8, 3.2];   // MAX98357 breakout
SPK_D    = 20;  SPK_T = 3.6;    // speaker
BS       = [25, 25, 1.1];       // beam splitter plate (v0.6: 25x25; a 30 mm plate collided with the lens)
MIR      = [30, 30, 1.6];       // first-surface mirror, 1 pc
LENS_D   = 30;  LENS_T = 6.5;   // biconvex f=50
BTN      = [6, 6, 5];           // tact switch body
BAT      = [40, 20, 8];         // battery pocket (y, z, x): edit when the cell is known
S_TAP    = 2.4;  S_CLR = 2.9;  S_HEAD = 5.4;  // M2.5x12 in PLA
CLR      = 0.4;  WALL = 1.6;

// ---------------------------------------------------------------- layout ---
FRONT_T  = 6;                  // rim plate depth (y 0..6)
BAR_T    = 8;                  // brow bar depth (y 0..8): the 5x5 wire groove leaves a 3 mm web
BAR_Z0   = 6;   BAR_Z1 = 22;   // brow bar z-range
GROOVE   = [5, 5];             // wire groove w (z) x d (y), on the back of the bar
GROOVE_Z = 11;
// hood (right, over the eye): OLED + mirror + lens, open at the top
HOOD_X0  = 13;  HOOD_X1 = 68;  // x 13..68 (68 = 2 mm INTO the right pod -> fused); 13 so the Ø30.8 lens pocket leaves a 2 mm end wall
HOOD_Y1  = 35;                 // depth y 0..35 (lens pocket Ø30.8 around y = 17.5 leaves 2 mm walls)
HOOD_Z0  = 4;   HOOD_Z1 = 38;  // z 4..38
BEAM_Z   = 22;                 // optical axis height in the hood
AX_Y     = 17.5;               // optical axis y (mirror, lens, splitter all on y = 17.5)
MIR_C    = [EX, AX_Y, BEAM_Z]; // mirror centre; plane at 45° about Y turns the -X beam to -Z
LENS_Z   = 13.4;               // lens centre z (axis Z)
COMB     = [EX, AX_Y, 0];      // splitter centre on the pupil axis, tilted 45° about X, top toward +Y
OLED_X0  = 60;  OLED_X1 = 66;  // OLED slide range (screen face x): do = (x-EX) + (BEAM_Z-LENS_Z) = 37.1..43.1
OLED_X   = 63;                 // nominal -> do = 40.1
// pods
POD_R    = [30, 46, 42];       // right pod (amp + button + wires)
POD_L    = [32, 64, 42];       // left pod (XIAO + battery)
POD_Z0   = -4;
POD_RX   = 66 + POD_R[0]/2;    // right pod centre x (inner wall at 66)
POD_LX   = -(66 + POD_L[0]/2);
POD_RY   = 6;                  // right pod y-range -17..29
POD_LY   = 2;                  // left pod y-range -30..34
// hinge, M2.5x12 from the top: bottom knuckle 8 tapped, temple 5, top 2, gaps 0.5 -> 4 mm of thread, head proud
HK_Z0 = 12; HK_BOT = 8; HK_TEMPLE = 5; HK_TOP = 2; HK_GAP = 0.5;
HK_R  = 5;                     // knuckle radius (bore 2.9 -> 3.5 mm wall)
TEMPLE_W = 12;  TEMPLE_H = 14;
LID_T    = 2.4;
BACK_W   = WALL + 1.4;         // pod back wall 3 mm (carries the hinge)

// --------------------------------------------------------------- helpers ---
module rbox(size, r=2) { hull() for (i=[-1,1], j=[-1,1], k=[-1,1]) translate([i*(size[0]/2-r), j*(size[1]/2-r), k*(size[2]/2-r)]) sphere(r=r, $fn=48); }
module rboxc(p, size, r=2) translate(p + size/2) rbox(size, r);
module plate(d) rotate([90,0,0]) translate([0,0,-d]) linear_extrude(height=d) children(); // 2D (x,z) -> +y 0..d
module lens2d(mir=false) scale([mir ? -1 : 1, 1]) offset(r=3) offset(r=-3)
    polygon([[DBL/2,6],[54,6],[56,-3],[52,-17],[42,-24],[22,-25],[DBL/2+4,-20],[DBL/2,-7]]);
module tap(l)  cylinder(d=S_TAP, h=l);
module clr(l)  cylinder(d=S_CLR, h=l);
module head(l=3) cylinder(d=S_HEAD, h=l);
function pod_c(s)   = s>0 ? [POD_RX, POD_RY, POD_Z0+POD_R[2]/2] : [POD_LX, POD_LY, POD_Z0+POD_L[2]/2];
function pod_sz(s)  = s>0 ? POD_R : POD_L;
function hinge_x(s) = pod_c(s)[0];
function hinge_y(s) = pod_c(s)[1] - pod_sz(s)[1]/2 - 5;   // axis 5 mm behind the pod back wall
function hood_boss_pts() = [[HOOD_X0+WALL+3, WALL+3], [HOOD_X1-WALL-3, WALL+3], [HOOD_X0+WALL+3, HOOD_Y1-WALL-3], [HOOD_X1-WALL-3, HOOD_Y1-WALL-3]];
function pod_boss_pts(s) = let(c = pod_c(s), sz = pod_sz(s))
    [[c[0]-sz[0]/2+WALL+3, c[1]-sz[1]/2+BACK_W+3], [c[0]+sz[0]/2-WALL-3, c[1]-sz[1]/2+BACK_W+3],
     [c[0]-sz[0]/2+WALL+3, c[1]+sz[1]/2-WALL-3],   [c[0]+sz[0]/2-WALL-3, c[1]+sz[1]/2-WALL-3]];
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

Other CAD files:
glass-fit-test-v0.3/temple_r.stl
glass-fit-test-v0.3/temple_l.stl
glass-fit-test-v0.2/pegs.stl
glass-fit-test-v0.2/pod_l.stl
cad/glass.blend
glass-fit-test-v0.2/front.stl

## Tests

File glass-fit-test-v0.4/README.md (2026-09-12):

# do-druku — przymiarka v0.4 (bez elektroniki)

Trzy części + 2 śrubki M2,5×12. Pody są zrośnięte z frontem (v0.2 miało osobne pody, które nie trzymały).
Folder jest kopią `cad/stl/` — źródłem jest `cad/glass.scad`.

| Plik | Szt. | Orientacja na stole | Podpory |
|---|---|---|---|
| `front.stl` | 1 | **tyłem do stołu** (płaska strona, ta od twarzy, w dół) | auto (tree): pod tylnymi połówkami podów i pod noskówkami |
| `temple_r.stl`, `temple_l.stl` | 1+1 | **płasko na boku** (szeroką ścianą do stołu) | trochę pod zagięciem, auto OK |

Ustawienia: PLA, 0,2 mm, **3 ścianki**, wypełnienie 20 %. Skala 1:1 (model dla PD = 62 mm, roboczo).
Front ma 200 mm szerokości — na X1C wchodzi po przekątnej lub wzdłuż X.

## Montaż

1. Zausznik: jego kostka wchodzi między dwie kostki z tyłu poda (dolna jest gwintowana przez śrubę).
2. **M2,5×12 z góry** przez górną kostkę poda, kostkę zausznika, wkręcasz w dolną kostkę. Otwór 2,4 mm — śruba sama nacina gwint w PLA. Zausznik ma się obracać; jak śruba trze, poluzuj ćwierć obrotu.
3. Pokrywek podów nie drukujemy do przymiarki (są w `cad/stl/lid_*.stl`, 4 × M2,5 każda, na potem).

## Zmiany od v0.3 (HUD na osi wzroku)

- wiązka biegnie tunelem w daszku i **drugie lusterko** w daszku zawraca ją w dół
- beam splitter **pochylony 45° przed prawym okiem**, dokładnie na osi źrenicy: patrzysz prosto, HUD nałożony na świat
- daszek 26 mm wysoki i 33 mm głęboki (mieści lusterko 30×30 pod kątem), pody głębsze o 6 mm
- OLED stoi w prawym podzie pionowo (obraz obraca się dwa razy), XIAO z kamerą i USB-C przeniesione do lewego poda

## Zmiany od v0.2 (po pierwszej przymiarce Jurka)

- pody zrośnięte z frontem: zero złącza, zero kołków od spodu, zero dziur w narożnikach
- tylko M2,5×12; otwory 2,4 (gwint) / 2,9 (przelot)
- front wygięty 6° (każda połowa przy mostku), większe otwory na szkła
- zauszniki: jedna gładka krzywa ze zwężeniem
- nic nie wchodzi od spodu

## Co sprawdzić po założeniu

- Czy nadal widać obręcze w polu widzenia → ewentualnie `WRAP` 6 → 9 albo `VD` 18 → 16.
- Szczelina pod daszkiem przed prawym okiem (na beam splitter) — czy nic nie dotyka rzęs (ma być ≥ 8 mm od oka).
- Noskówki: symetria, czy oprawka opada.
- Zauszniki: ucisk przed uszami (`TEMPLE_SPLAY`), miejsce zgięcia (`TEMPLE_L`), czy hak trzyma za uchem.

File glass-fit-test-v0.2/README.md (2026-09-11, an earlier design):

# do-druku — przymiarka v0.2 (bez elektroniki)

Zestaw do sprawdzenia dopasowania na głowie. Bez pokrywek podów (niepotrzebne do przymiarki)
i bez śrubek: zamiast M2,5 są drukowane kołki. Folder jest kopią `cad/stl/` — źródłem jest `cad/glass.scad`.

| Plik | Szt. | Orientacja na stole | Podpory |
|---|---|---|---|
| `front.stl` | 1 | **tyłem do stołu** (płaska płaszczyzna y=0 w dół, daszek do góry) | tylko pod noskówkami (wystają 4,5 mm za tył), auto-podpory OK |
| `pod_r.stl`, `pod_l.stl` | 1+1 | **na ściance wewnętrznej** (ta z prostokątnym gniazdem), otwarta komora do góry | małe pod kostkami zawiasu z tyłu |
| `temple_r.stl`, `temple_l.stl` | 1+1 | **na boku** (płasko, szeroką ścianą do stołu), hak leży | pod hakiem trochę, auto OK |
| `pegs.stl` | 1 (6 kołków) | leżą płasko, jak wyeksportowane | brak |

Ustawienia: PLA (czarny/ciemnoszary), 0,2 mm, **3 ścianki**, wypełnienie 20 %, bez rafu pod frontem.
Skala: **1:1, nic nie skalować.** Cały model jest policzony dla PD = 62 mm (roboczo).

## Montaż do przymiarki

1. Końcówka daszka (prawa strona frontu) wchodzi w prostokątne gniazdo prawego poda; lewy koniec belki w gniazdo lewego poda. Cztery **krótkie kołki (10 mm)** wciskasz od spodu podów w otwory — wchodzą ciasno, lekko rozwiercić 2 mm wiertłem, jeśli nie chcą.
2. Zausznik: kostka zausznika między dwie kostki poda, **długi kołek (43 mm)** z góry przez wszystkie trzy. Ma się obracać.
3. Jeśli masz jakiekolwiek śrubki M2,5 lub M3 — kołki są tylko zastępstwem.

## Co sprawdzić po założeniu i zapisać (mm)

- Czy noskówki dotykają nosa symetrycznie, czy oprawka opada / uciska.
- Odległość szkieł od rzęs (ma być ≥ 8 mm). Jeśli za blisko → `VD` w SCAD w górę.
- Czy zauszniki uciskają głowę przed uszami (→ `TEMPLE_SPLAY` w górę) albo są luźne (w dół).
- Gdzie zaczyna się zgięcie względem góry ucha (→ `TEMPLE_L`).
- Czy pody nie dotykają skroni.

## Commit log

2026-09-11 v0.1 — print-ready parametric frame (OpenSCAD) + Blender renders
    [glass.blend, glass.scad]
2026-09-11 renders: final v0.1 stills + turntable, reference folder for head scan
    [glass.blend]
2026-09-11 fit to head scan: VD 18, DBL 18, angled nose pads; renders on the real face; scan kept local
    [glass.scad]
2026-09-11 temples: length from ear scan (55 mm), 13° splay, hook over the ear; renders on the full-head scan
    [glass.scad]
2026-09-11 temples: 63 mm to the bend, longer ear hooks (Jurek: ears sit further back)
    [glass.scad]
2026-09-11 v0.2 fit-test print set: rounded pods/brow/temples, printed pegs instead of screws, do-druku/ with print guide
    [front.stl, glass.scad, pegs.stl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]
2026-09-11 pods: flat inner faces so the front meets them flush (no gaps); fit-test STLs regenerated
    [front.stl, glass.scad, pegs.stl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]
2026-09-11 exploded view for assembly instructions
    [front.3mf, front.stl, glass.scad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]
2026-09-11 v0.3: pods fused into the front, M2.5x12 hinge, 6° wrap, larger lenses, smooth temples, fit-test set
    [front.stl, pegs.stl, pod_l.stl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]
2026-09-12 v0.4: HUD on the line of sight — hood mirror, splitter tilted 45° in front of the eye, portrait OLED, XIAO moved to the left pod
    [front.stl, temple_l.stl, temple_r.stl]
2026-09-12 site: G.L.A.S.S. landing + learn more (HUD framebuffer, optics steps, explorer, simulator, GLB viewer, versions), render-site pipeline; cad v0.5 fixes (flat back, hinge bore, blind lens pocket)
    [front.3mf, front.stl, temple_l.stl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]
2026-09-12 site: v0.5 placeholder renders (96 turntable frames, stills, GLB), Pillow webp pipeline
2026-09-12 v0.6: single-fold optics (OLED in the hood, one mirror, lens above the 25 mm combiner), open-top hood/pods with lids, 4 mm hinge thread, outward temple splay, VD 21; gauntlet report; shopping list up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
    [front.stl, glass.scad, temple_l.stl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]
2026-09-12 do-druku: v0.6 print set
    [front.stl, lid_hood.stl, lid_l.stl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]
2026-09-12 site: optics diagram shows the splitter reflecting into the eye (v0.6 single-fold path)
    Blender script updated for v0.6: hood lid imported, splitter on the pupil axis,
    camera and LED in the left pod, no wrap.
2026-09-12 site: v0.6 placeholder renders (hood lid, splitter on axis, camera in left pod)
2026-09-12 Gzowo Industries: umbrella site with G.L.A.S.S. and Smendilendi
    - home at industries.gzowo.fun, product pages under /glass and /smendilendi
    - hero renders framed wider (nothing cropped), button visible on the pod lid
    - optics diagram redrawn as a real side view of the glasses
    - three.js importmap so the GLB viewer loads
    - assistant simulator: factual, dry tone
    - Smendilendi v0.5 renders, turntable and GLB
